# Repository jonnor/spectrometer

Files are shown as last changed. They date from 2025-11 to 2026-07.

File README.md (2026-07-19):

# Simple spectrometer for edible oils

This is a simple setup for a basic 14 channel visible-spectrum
sensor based on [ams OSRAM AS7343](https://ams-osram.com/products/sensor-solutions/ambient-light-color-spectral-proximity-sensors/ams-as7343-spectral-sensor),
using [MicroPython](https://micropython.org/) firmware.

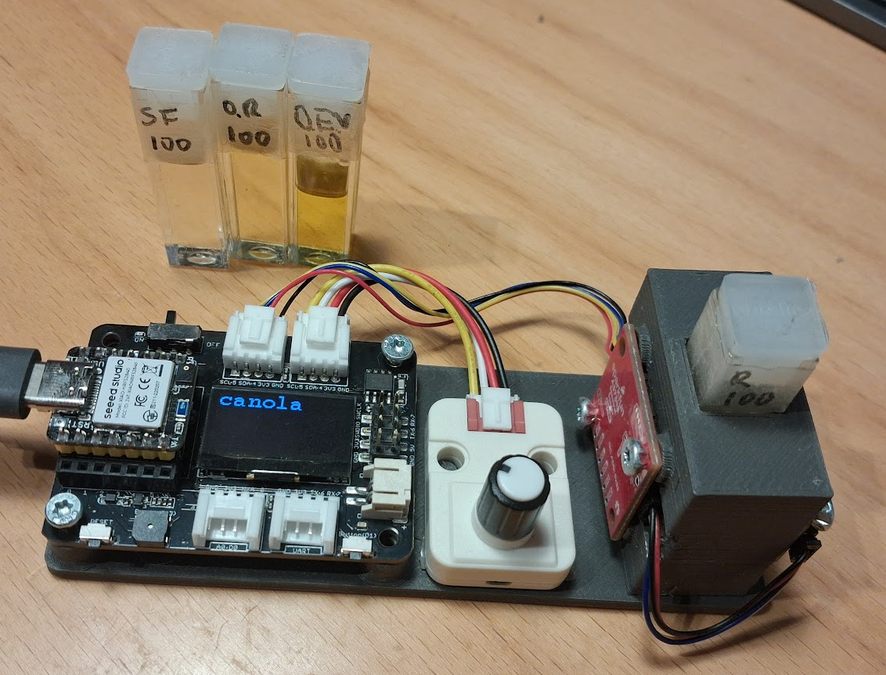
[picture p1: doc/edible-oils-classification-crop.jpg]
Classification of edible oil


The device has a stand designed for standard (10 mm) cuvettes,
set up for flouresence spectrocopy using white LED and reflectance spectroscopy using white LED.

Initially intended for characterization of edible oils,
such as olive oil, canola/rapeseed, sunflower, et.c.

This can be used for things like:

- Detect/classify the type of oil
- Detect adulterated oils, for example addition of waste frying oil or other oils in virgin olive oil
- Detect degraded oil quality, for example due to exessive oxygen/heat exposure or age

The machine learning parts are powered by [emlearn-micropython](https://github.com/emlearn/emlearn-micropython),
a machine learning and digital signal processing library for MicroPython.

## Status
*Proof of Concept*. 

Can collect data from AS7343, and classify the type pf edible successfully using a nearest-neighbor model.
For the demo only 2 dimensions were used, but up to 2x12=24 dimensions can be used.

[Short demo video (YouTube)](https://youtube.com/shorts/O7MoSn06O6k).

## TODO

- Speed up the measurement cycle. Want under 1 second total
- Collect data on different concentrations of oil. 
- Test ability to detect adulteration of extra virgin olive oil
- Implement regression model to estimate concentrations. Example: PCA+linreg, or PLSR

## Operating principle

The device measures the samples under 2 conditions:

- When exposed to white light from same side as sensor (reflectance)
- When exposed to 400 nm UV light from the side (floursence)

Many edible oils have a
Extra Virgin Olive Oil (EVOO) notably has a red-ish response under UV,
which comes from the chlorophyll. This is not present in refined olive oil.

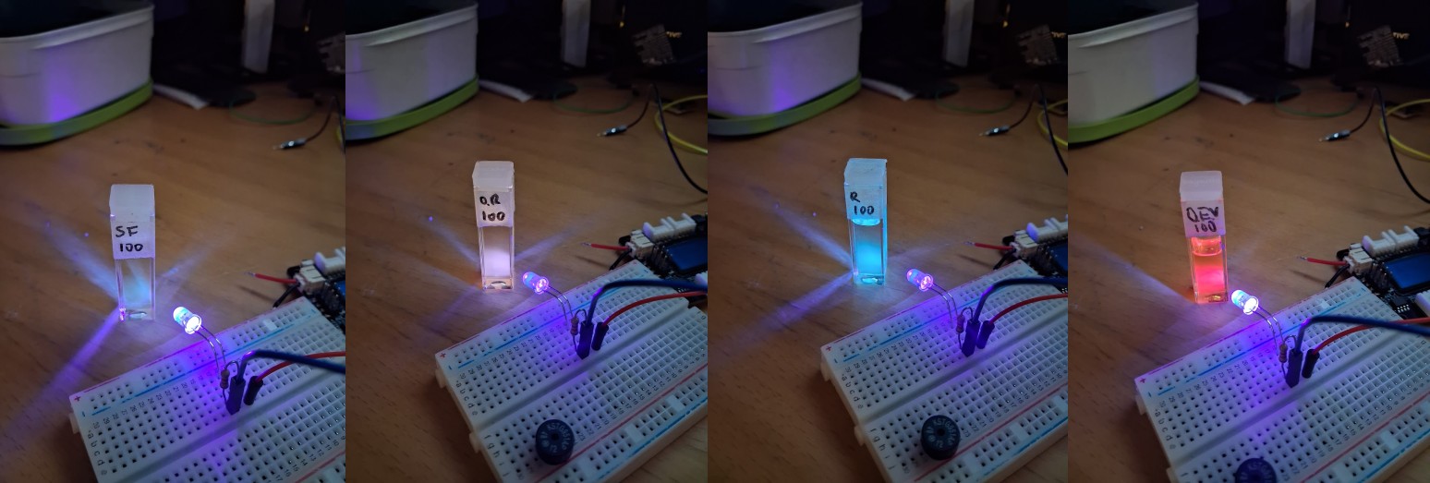
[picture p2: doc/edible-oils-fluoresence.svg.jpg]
Edible oils under 400nm


The AS7343 has 12 narrow-band channels across the visible spectrum and near-infrared (NIR),
plus 2 broad-band channels.

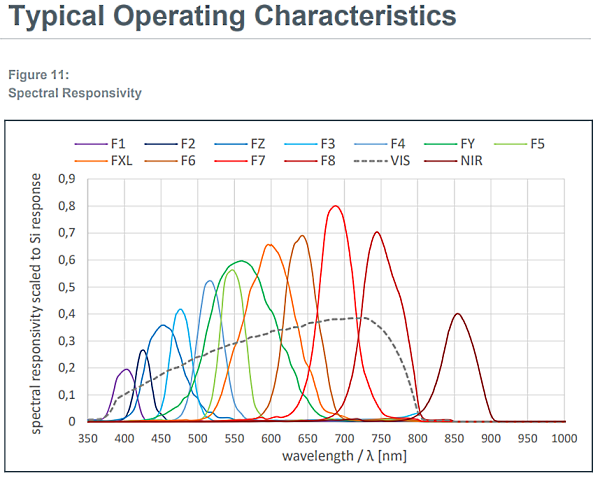
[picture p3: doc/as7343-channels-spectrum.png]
AS7343 channels spectral response


## Hardware

Below is the parts that I have used.
The AS7343 chip is critical, and a microcontroller that can run MicroPython.
If you are willing to adapt the firmware code the other parts can be replaced
with other alternatives relatively easily.

#### Electronics

- [SparkFun Spectral Sensor - AS7343 (Qwiic)](https://www.sparkfun.com/sparkfun-spectral-sensor-as7343-qwiic.html)
- [Seeed Studio XIAO NRF52840](https://www.seeedstudio.com/Seeed-XIAO-BLE-nRF52840-p-5201.html). Optional: Sense variant
- [Adafruit AW9523 GPIO Expander and LED Driver Breakout - STEMMA QT / Qwiic](https://www.adafruit.com/product/4886)
- [Seeed Studio Expansion Board Base for XIAO](https://www.seeedstudio.com/Seeeduino-XIAO-Expansion-board-p-4746.html)
- [M5Stack Unit Encoder - I2C with Grove connector](https://docs.m5stack.com/en/unit/encoder)
- 400 nm UV LED, 5mm
- 1x Grove to Qwiic / Stemma QT adapter cable
- 1x Qwiic / Stemma QT cable
- 1x Grove cable (NOTE: often included with Grove devices)

All should be available from Digikey.

#### Mechanics

- 10 mm light-path cuvettes (12.5x12.5x45 mm / 4.5 ml)
- M3 wood/plastic screws

#### 3d-printed parts

- Base board for XIAO. [STEP]() | [FreeCAD]()
- Cuvette holder. [STEP]() | [FreeCAD]()

## Firmware

#### Install MicroPython

For the XIAO NRF52840 I used the Zephyr port of MicroPython.
As of November 2025 it is not downloadable on micropython.org, but must be built.

#### Install dependencies

External dependencies
```
mpremote mip install os-path
mpremote mip install github:pimoroni/as7343-micropython
mpremote mip install github:jonnor/micropython-npyfile
mpremote mip install github:peterhinch/micropython-nano-gui
mpremote mip install "github:peterhinch/micropython-nano-gui/drivers/ssd1306"
mpremote mip install https://emlearn.github.io/emlearn-micropython/builds/latest/armv6m_6.3/emlearn_neighbors.mpy
```

Local files
```
mpremote cp -r firmware/* :
```

Run 
```
mpremote run firmware/spectrometer_main.py
```

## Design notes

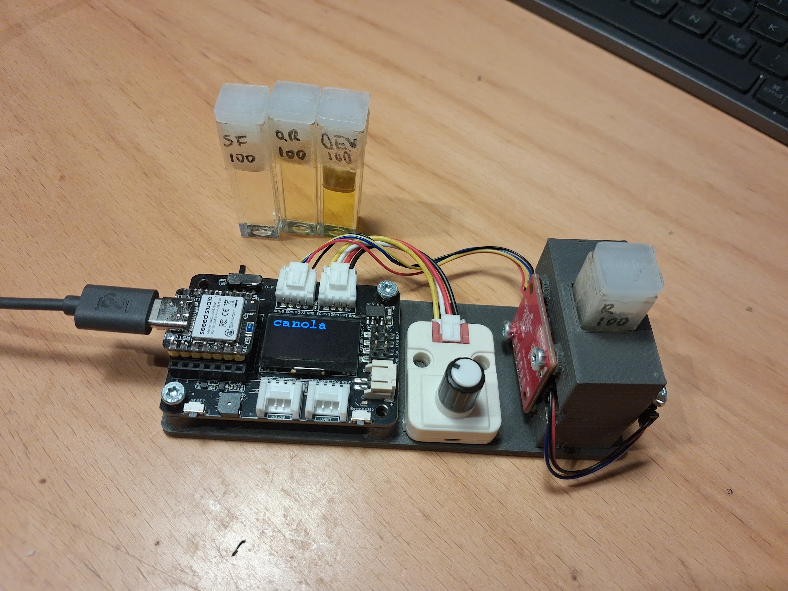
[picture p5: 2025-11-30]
doc/edible-oils-classification.jpg

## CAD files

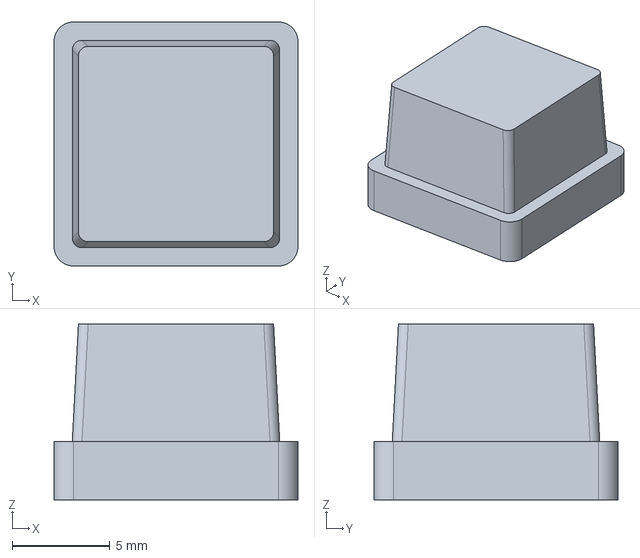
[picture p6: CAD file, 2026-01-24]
mechanics/cuvette-stopper.FCStd
12.5 x 12.5 x 9.00 mm

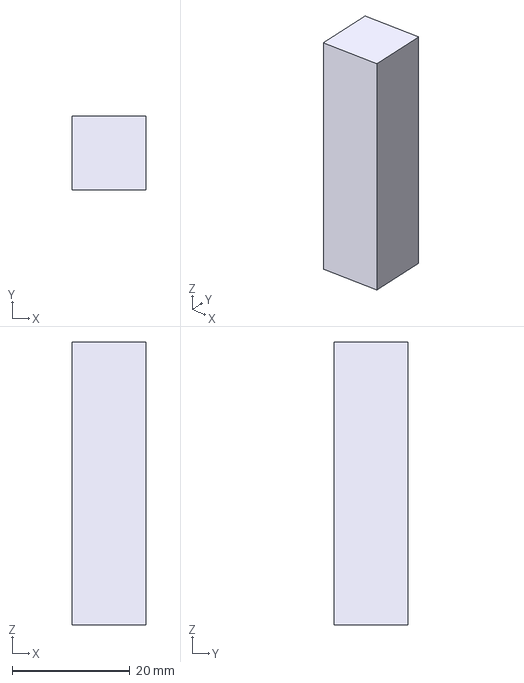
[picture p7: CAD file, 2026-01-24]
mechanics/cuvette.step
12.5 x 12.5 x 48.0 mm

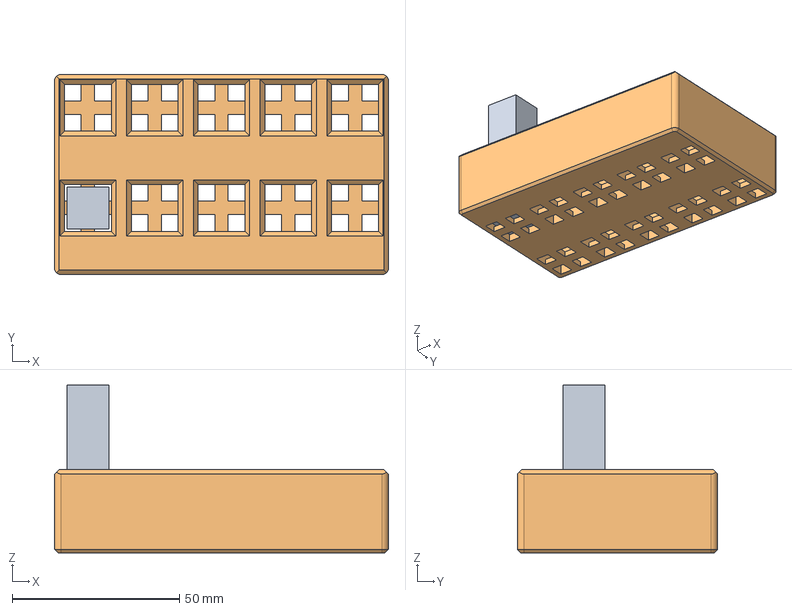
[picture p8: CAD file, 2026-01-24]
mechanics/cuvette-rack.FCStd
100.0 x 60.0 x 50.2 mm

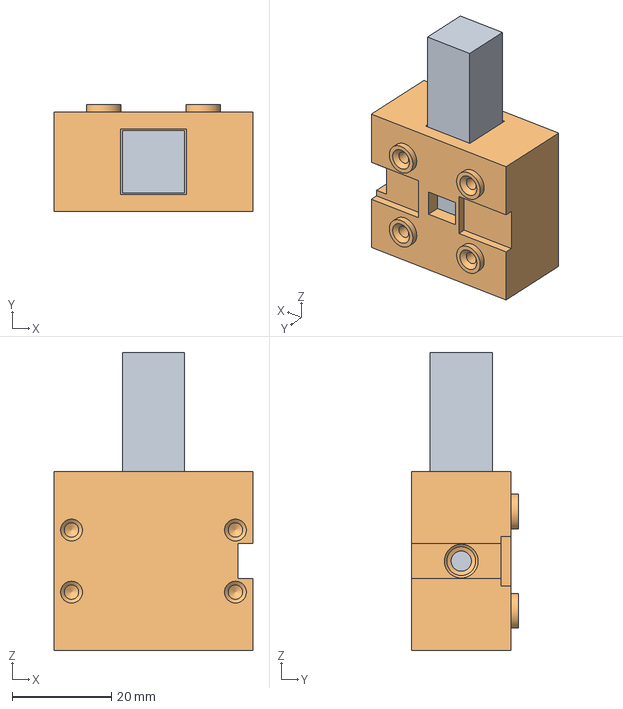
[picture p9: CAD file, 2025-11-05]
mechanics/cuvette-as7343.FCStd
40.0 x 21.5 x 60.0 mm

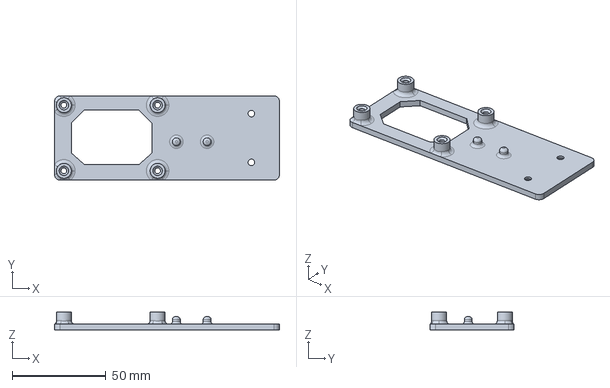
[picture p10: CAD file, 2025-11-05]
mechanics/xiao-extension-base.FCStd
120.0 x 45.0 x 9.40 mm

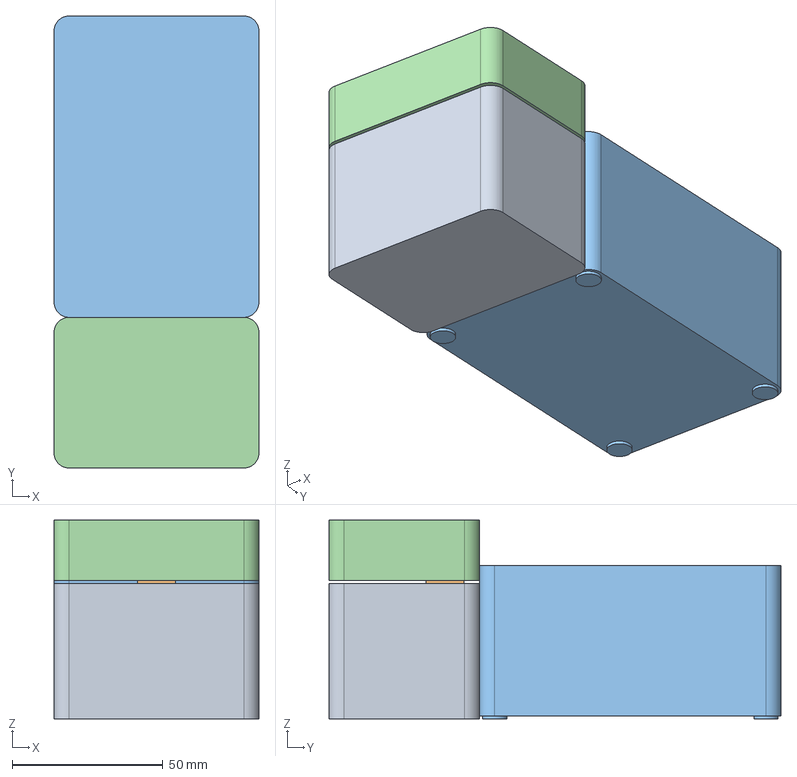
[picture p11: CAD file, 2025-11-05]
mechanics/cuvetteholder.FCStd
68.0 x 150.0 x 66.0 mm

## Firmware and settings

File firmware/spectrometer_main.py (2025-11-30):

import time
import machine
import array
import asyncio
import math
import os.path
import gc

from aw9523 import AW9523
from as7343 import AS7343
from encoder import M5StackEncoder
import npyfile

from machine import Pin, SoftI2C


from color_setup import ssd, display_height, display_width  # Create a display instance
from gui.core.nanogui import refresh
from gui.core.writer import Writer
from gui.widgets.meter import Meter
from gui.widgets.label import Label
import gui.fonts.courier20 as fixed

# Free memory used by imports
gc.collect()

def draw_hlines(ssd, x0, x1, y0, y1, lines=10, dash=5, gap=2, color=1):

    y_dist = int((y1-y0) / lines)
    for y in range(y0, y1, y_dist):
        
        # dashed
        for x in range(x0, x1, dash + gap):
            ssd.hline(x, y, min(dash, x1-x), color)

def draw_vlines(ssd, x0, x1, y0, y1, lines=10, dash=5, gap=2, color=1):

    x_dist = int((x1-x0) / lines)
    for x in range(x0, x1, x_dist):
        
        # dashed
        for y in range(y0, y1, dash + gap):
            ssd.vline(x, y, min(dash, y1-y), color)

class NeighborsClassifier():

    def __init__(self,
            columns : list[int],
            classes : list[str],
            max_items=100,
            n_neighbors=1,
        ):

        self.classes = classes
        self.columns = columns

        import emlearn_neighbors
        self.model = emlearn_neighbors.new(max_items, len(columns), n_neighbors)

        print('c', self.columns)

    def load_data(self, data_dir : str):

        for filename in os.listdir(data_dir):
            p = os.path.join(data_dir, filename)
            shape, data = npyfile.load(p)
            assert len(shape) == 1, shape

            tok = filename.split('-')
            classname = tok[0]
            if classname == 'unknown':
                continue
            x = self.transform(data)
            y = self.classes.index(classname)
            print('load-item', classname, y, x)
            self.model.additem(x, y)

    def transform(self, data):
        # Extract the relevant columns
        # TODO: maybe also do a log transform?
        values = array.array('h', ( int(data[i]) for i in self.columns ))
        return values

    def predict(self, measurement):
        # TODO: also check how close the closest point is?
        x = self.transform(measurement)
        print('predict', x)
        out = self.model.predict(x)
        return out


def update_screen(n, state, data, x_column, y_column, prediction, x_max=10000, y_max=500):


    # Blank the screen
    ssd.fill(0)

    x_offset = 0
    y_offset = 5

    width = display_width
    height = display_height

    if state == 'done':

        # Draw grid
        draw_hlines(ssd, x0=x_offset, x1=width, y0=y_offset, y1=height, lines=5, gap=8, dash=1)
        #draw_vlines(ssd, x0=x_offset, x1=width, y0=y_offset, y1=height, lines=10, gap=8, dash=1)

        # Draw datapoints
        print('draw-datapoints', len(data), x_column, y_column)
        x_paper = data[x_column] / x_max
        y_paper = data[y_column] / y_max
        
        if x_paper < 0.0 or x_paper > 1.0 or y_paper < 0.0 or y_paper > 1.0:
            print('point-out-of-bounds', x_paper, y_paper)

        x = int(x_paper * width)
        y = int(y_paper * height)
        color = 1
        size = 7

        print('draw-point', data[x_column], data[y_column], x, y)
        # Draw a small point
        ssd.fill_rect(x + x_offset, y + y_offset, size, size, color)

    elif state == 'result':

        Writer.set_textpos(ssd, 0, 0)
        wri = Writer(ssd, fixed, verbose=False)
        wri.set_clip(False, False, False)

        # TODO: center this
        textfield = Label(wri, 0, 2, wri.stringlen(prediction))
        textfield.value(prediction)        

    else:
        text = state

        Writer.set_textpos(ssd, 0, 0)
        wri = Writer(ssd, fixed, verbose=False)
        wri.set_clip(False, False, False)

        textfield = Label(wri, 0, 2, wri.stringlen(text))
        textfield.value(text)

    refresh(ssd)

async def measure_one(as7343, data, offset=0, wait_time=1.0):

    order = AS7343.CHANNEL_MAP

    # wait for condition to settle
    await asyncio.sleep(wait_time)

    # XXX: make sure to flush out old readings from FIFO
    for i in range(10):
        readings = as7343.read()
        await asyncio.sleep(0.10)

    # Copy data
    for i, c in enumerate(order):
        data[offset+i] = readings[c]

    await asyncio.sleep(wait_time)

async def measure_sample(i2c_ext, ext, data, wait_time=1.0):
    """
    Make one complete measurement, consisting of 3 sub-measurements:

    - no excitation / baseline
    - UV excitation / flouresence
    - white / reflectance

    The values are concatenated
    """
    
    as7343 = AS7343(i2c_ext)

    as7343.set_measurement_time(200) # ms
    as7343.set_integration_time(100*1000, repeat=1) # us
    as7343.set_illumination_led(False)
    as7343.set_illumination_current(4)

    n_channels = len(AS7343.CHANNEL_MAP)
    n_datapoints = n_channels * 3
    assert len(data) == n_datapoints

    start = time.ticks_ms()
    print('measure-sample-start', start)

    as7343.start_measurement()
    await asyncio.sleep(0.1)   

    # measure without exitation
    #print('measure-no-light')
    #ext[0:16] = 0
    #await measure_one(as7343, data, offset=0, wait_time=wait_time)

    # Measure with UV exitation
    print('measure-uv')
    ext[0:16] = 100
    await measure_one(as7343, data, offset=n_channels, wait_time=wait_time)
    ext[0:16] = 0

    # Measure with white LED
    #print('measure-white')
    #as7343.set_illumination_led(True)
    #await measure_one(as7343, data, offset=2*n_channels, wait_time=wait_time)
    #as7343.set_illumination_led(False)

    as7343.stop_measurement()

    duration = time.ticks_diff(time.ticks_ms(), start)
    print('measure-sample-end', time.ticks_ms(), duration)



def main():

    i2c_int = machine.I2C("i2c0")

    i2c_ext = machine.I2C("i2c1")
    ext = AW9523(i2c_ext, address=0x5b)


    measurement_data = array.array('f', (0.0 for _ in range(3*len(AS7343.CHANNEL_MAP))))

    shape, measurement_data = npyfile.load('data2/channels-13800.npy')
    print('loaded-data', shape, len(measurement_data))

    encoder = M5StackEncoder(i2c_ext)
    accumulated = 0.0
    iteration = 0

    data_dir = 'data3'
    if not os.path.exists(data_dir):
        os.mkdir(data_dir)

    classes = [
        'none',
        'sunflower',
        'canola',
        'EVOO',
        'ROO',
    ]
    last_prediction = None

    uv_start = len(AS7343.CHANNEL_MAP)*1
    x_index = uv_start + AS7343.CHANNEL_MAP.index('F7')
    y_index = uv_start + AS7343.CHANNEL_MAP.index('FZ')
    classifier = NeighborsClassifier(classes=classes, columns=[x_index, y_index])
    classifier.load_data(data_dir)

    #classifier.predict(measurement_data)

    measurement_state = 'ready'
    #measurement_state = 'done'

    selected_class = 'unknown'

    async def check_inputs():

        nonlocal measurement_state
        nonlocal accumulated
        nonlocal iteration
        nonlocal last_prediction

        while True:

            button = encoder.read_button()
            if button:
                if measurement_state == 'ready':
                    measurement_state = 'measure'

                    gc.collect()
                    await measure_sample(i2c_ext, ext, data=measurement_data, wait_time=0.2)

                    filename = selected_class + '-channels-' + str(time.time()) + '.npy'
                    path = os.path.join(data_dir, filename)
                    shape = (len(measurement_data),)
                    npyfile.save(path, measurement_data, shape=shape)
                    print('measurement-saved', path)

                    measurement_state = 'done'
                    await asyncio.sleep(2.0)

                    class_idx = classifier.predict(measurement_data)
                    class_name = classifier.classes[class_idx]
                    last_prediction = class_name
                    print('predict-result', class_idx, class_name)
                    measurement_state = 'result'
                    await asyncio.sleep(2.0)

                    measurement_state = 'ready'
                else:
                    print('button-ignored', measurement_state)

            rel = encoder.read_relative()
            accumulated += rel

            iteration += 1
            await asyncio.sleep(0.010)

    async def make_measurement():

        while True:
            # XXX: does nothing right now
            pass
            await asyncio.sleep(5.0)


    async def update_display_loop():

        while True:

            start = time.ticks_ms()
            if True:
                update_screen(n=iteration,
                    state=measurement_state,
                    data=measurement_data,
                    x_column=x_index,
                    y_column=y_index,
                    prediction=last_prediction,
                )
                duration = time.ticks_diff(time.ticks_ms(), start)
                print('screen-update', duration)
            await asyncio.sleep(0.5)

    async def run():
        await asyncio.gather(update_display_loop(), check_inputs(), make_measurement())
    asyncio.run(run())


if __name__ == '__main__':
    main()

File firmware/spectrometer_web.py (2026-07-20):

import os
import struct
import asyncio
import time
import array
import gc
import json
import math

from microdot import Microdot, Response, send_file
from aw9523 import AW9523
from as7343 import AS7343
import npyfile

import processing
from measure import MeasurementService

# Free memory used by imports
gc.collect()


# ---------------------------------------------------------------------------
# WiFi
# ---------------------------------------------------------------------------

async def _connect_wifi():
    """Connect to WiFi using credentials from secrets.py.
    No-op on non-device platforms where the network module is unavailable."""
    try:
        import network
    except ImportError:
        return

    import secrets

    wlan = network.WLAN(network.STA_IF)
    wlan.active(True)

    if wlan.isconnected():
        print('WiFi already connected:', wlan.ifconfig()[0])
        return

    print('Connecting to WiFi SSID: {} ...'.format(secrets.SSID))
    wlan.connect(secrets.SSID, secrets.PASSWORD)

    while not wlan.isconnected():
        await asyncio.sleep(0.5)

    print('WiFi connected:', wlan.ifconfig()[0])

def add_routes(app, state):

    # User interface
    MAX_AGE = 1 # XXX: set longer in production, for more efficient caching

    @app.get('/')
    async def get_index(request):
        return send_file('frontend/index.html')

    @app.get('/static/<path:path>')
    async def get_static(request, path):
        return send_file('frontend/' + path, max_age=MAX_AGE)

    @app.get('/samples.json')
    async def get_samples(request):
        samples = []

        path = 'data/try2/data3/'
        for s in processing.load_samples(path):
            samples.append(s)

        return samples, 200

    @app.get('/status')
    async def get_status(request):
        progress_percent = 100*state.measurement.get_progress()
        s = {
            'connected': True,            
            'measuring': state.measurement.is_started(),
            'progress': progress_percent,
        }
        return s, 200

    @app.post('/measure')
    async def post_measure(request):

        # Trigger a measurement
        # will cause exception if multiple. TODO: convert to exception
        state.measurement.start()

        out = {}
        return out, 200


class AppState:
    def __init__(self, measurement):
        self.measurement = measurement


def main(host='0.0.0.0', port=8000, debug=True):

    print('app-load')

    # Web server
    app = Microdot()

    i2c = None
    gpio = None
    as7343 = None
    if False: # TODO: detect when on device
        from machine import Pin, I2C
        i2c = I2C(1, scl=Pin(5), sda=Pin(4), freq=400000)
        as7343 = AS7343(i2c_ext)
        gpio = AW9523(i2c_ext, address=0x5b)

    state = AppState(measurement=MeasurementService(as7343, gpio))

    from cors import CORS
    cors = CORS(app, allowed_origins='*', allow_credentials=False)

    add_routes(app, state)

    # Reduce memory pressure
    gc.collect()
    print('app-start', 'mem_free={}'.format(gc.mem_free()))

    # Actually start server
    async def _startup():
        await _connect_wifi()
        print('HTTP server on {}:{}'.format(host, port))
        await app.start_server(host=host, port=port, debug=debug)

    asyncio.run(_startup())

if __name__ == '__main__':
    main()

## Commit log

2025-11-05 Import from embeddedml repo
    [cuvette-as7343.FCStd, cuvetteholder.FCStd, xiao-extension-base.FCStd]
2026-01-23 mechanics: Add initial cuvette stopper
    Works but maybe a tad big
    [cuvette-stopper.FCStd]
2026-01-24 mechanics: Add a cuvette rack
    [cuvette-rack.FCStd, cuvette.step]
2026-01-24 mechanics: Make stopper bit less wide
    [cuvette-stopper.FCStd]
2026-07-20 Load existing samples from disk
